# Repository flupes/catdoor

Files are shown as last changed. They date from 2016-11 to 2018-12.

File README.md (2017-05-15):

# catdoor
Cat door opening detection and notification

## First version

Notification of cat entry only (catdoor locked so that the cat can never go out, but always come in). This allows to make sure the cat in inside before dark in case we are coming late home.

### Sensing

Based on a proximity sensor looking down where the door opens. Some reflective on the side of the door allow a ver good signature, sorting out the cat. In fact, test of reflectivity on the cat hairs shows very poor reflection. Tuning the system as been done by observing serveral opening (look in the data directory)

- Microcontroller with ESP8266 Wifi:[Adafruit Feather HUZZAH with ESP8266 WiFi](https://www.adafruit.com/product/2821)
- Breadkout sensor board: [VCNL4010 Proximity/Light sensor](https://www.adafruit.com/product/466)

### Notification

The Feather HUZZAH sends a mqtt message to a Beagle Bone Black (BBB), which in turn sends notifications to a cell phone using Push Bullet.

The HUZZAH sends periodic updates of the door status, thus the BBB is can also detect potential anomalies.

This architecture with the HUZZAH + BBB never exposes the ESP8266 on the internet (only local communication).

## Second version

### Goals

- Outgoing locking mechanism that only allows the cat to go out during full daylight
- Notification of door actuation in the two direction (in and out)

Design ideas in ./design.md

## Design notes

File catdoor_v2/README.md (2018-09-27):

# Intro

This is the source directory for the version 2 of the catdoor application.

The code under this directory is structured to be compiled with platformio.

```
catdoor_v2/
├── app            main catdoor application
├── libs           libraries
└── tests          test programs (development purpose)
```                  

# Dependencies

## libs via platformio
Install the following:
- WiFi101 by Arduini - http://www.arduino.cc/en/Reference/WiFi101
- PubSubClient by Nick O'Leary - https://github.com/knolleary/pubsubclient.git

## extra libs

To get extra custom libraries like my fork of RTClib, use:
```
git submodules init
git submodules update
```

# Build and Install

Compile with:

    pio run -v

Upload with:

    pio run -v --target upload

Serial Monitor:
    pio device list
    pio device monitor --port /dev/cu.usbmodem1421 --baud 115200
      # or on PC:
    pio device monitor --port COM29 --baud 115200

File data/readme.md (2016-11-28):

### Record serial port
```
screen -L /dev/cu.SLAB-USBtoUART 115200
```
Note: output is `screenlog.0`, will overwrite a previous one...

Terminate session with: `Ctrl-a + \`

### Procedure

The vcnl4010_test program was flashed on the ESP8266 to record data using
screen.

### Files

#### Results
[`door_entry_signatures.svg`](./door_entry_signatures.svg) : graph of the door opening signatures

[`cat_only_returns.svg`](./cat_only_returns.svg) : sensor with Misty playing under it (door closed)

#### Analysis
`door_signatures.ods` : analysis of the data (signature, timing,
background)

#### Logs
`misty_entry_and_stay.log` : log with one entry (kind of messed up because
Misty stop right under the sensor after entering since the treat was there)

`misty_2_entries.log` : log with two entries in the same file

`misty_entry_?.log` : short version (5 seconds around the event) of the
previous logs

`misty_only_?.log` : door closed, but Misty under the sensor (playing with
my hand)

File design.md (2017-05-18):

# Design of the CatDoor v2

## Requirements

- System based on the [SureFlap Microchip Cat Door](https://sureflap.com/en-us/pet-doors/microchip-cat-flap)
  - right size
  - seems reliable (tested one for 1 year + reviews)
- The RFID entry (from outside) mechanism is left untouched
  - keep the same IN reliability
- Allow exit only during daylight
  - need very high reliability in locking (OK to lock too often, not OK to not lock once) to avoid having the cat becoming a Mountain Lion snack
  - ideally, timer follow seasonal sunset - surise times
- Notify of entrance / exit pattern to get some peace of mind when away, and be able to re-act quicly if cat did not come in before dark.

## Locking Solutions

### Servo + feedback

The servo arm would have two position at 90 deg to lock/unlock the door. The servo can be turned off all the time but when switching mode because there is enough friction to leave the arm in place.

Since the servo would not provide a default locked position (loss of power or other issue), a servo with analog feedback would be used: each time the mode it switched we could get confirmation that the actual position has been reached.

#### Pro
- Simple solution and micro servo available (e.g. https://www.adafruit.com/product/1449)

#### Cons
- This is not a totatlly safe proof solution
- If power is loss, we are operating from the LiPo 3.7V, thus probably requiring a voltage booster to power the servo

### Linear solenoid + proximity sensor

A small pull solenoid (default plunger position out) would be retracted when the cat approach the door.

#### Pro
- Safest solution: when eveything fails, the door is locked and the cat cannot go outside

#### Con
- Requires a an extra sensor ang good signal to trigger the opening
- Not easy to source miniature solenoids operating at low voltages
s
## Notes

There are two ohter products that do already the right in/out control with timer:
- [Cat Mate Elite](https://www.amazon.com/Cat-Mate-Elite-Timer-Control/dp/B000XPSH34). However it only seems to work with RFID chips you put on a colar. And multiple reviews mentioned it is not reliable. Since we cannot afford to have the cat locked out a single time, this product does not seems an option for our usage.

- [SureFlap Microchip Pet Door](https://www.amazon.com/SureFlap-Microchip-Pet-Door-White/dp/B009NH6NR0/). However this product is much larger (Pet vs Cat) than a normal cat door.
  - Pet Door Dimensions:
    - Flap Opening: 6 11⁄16" (W) x 7" (H)
    - Exterior Frame: 10 5⁄16" (W) x 11 1⁄16" (H)
  - Cat Door Dimensions:
    - Flap Opening: 5 5⁄8" x 4 3⁄4"
    - Exterior Frame: 8 1⁄4" (W) x 8 1⁄4" (H)

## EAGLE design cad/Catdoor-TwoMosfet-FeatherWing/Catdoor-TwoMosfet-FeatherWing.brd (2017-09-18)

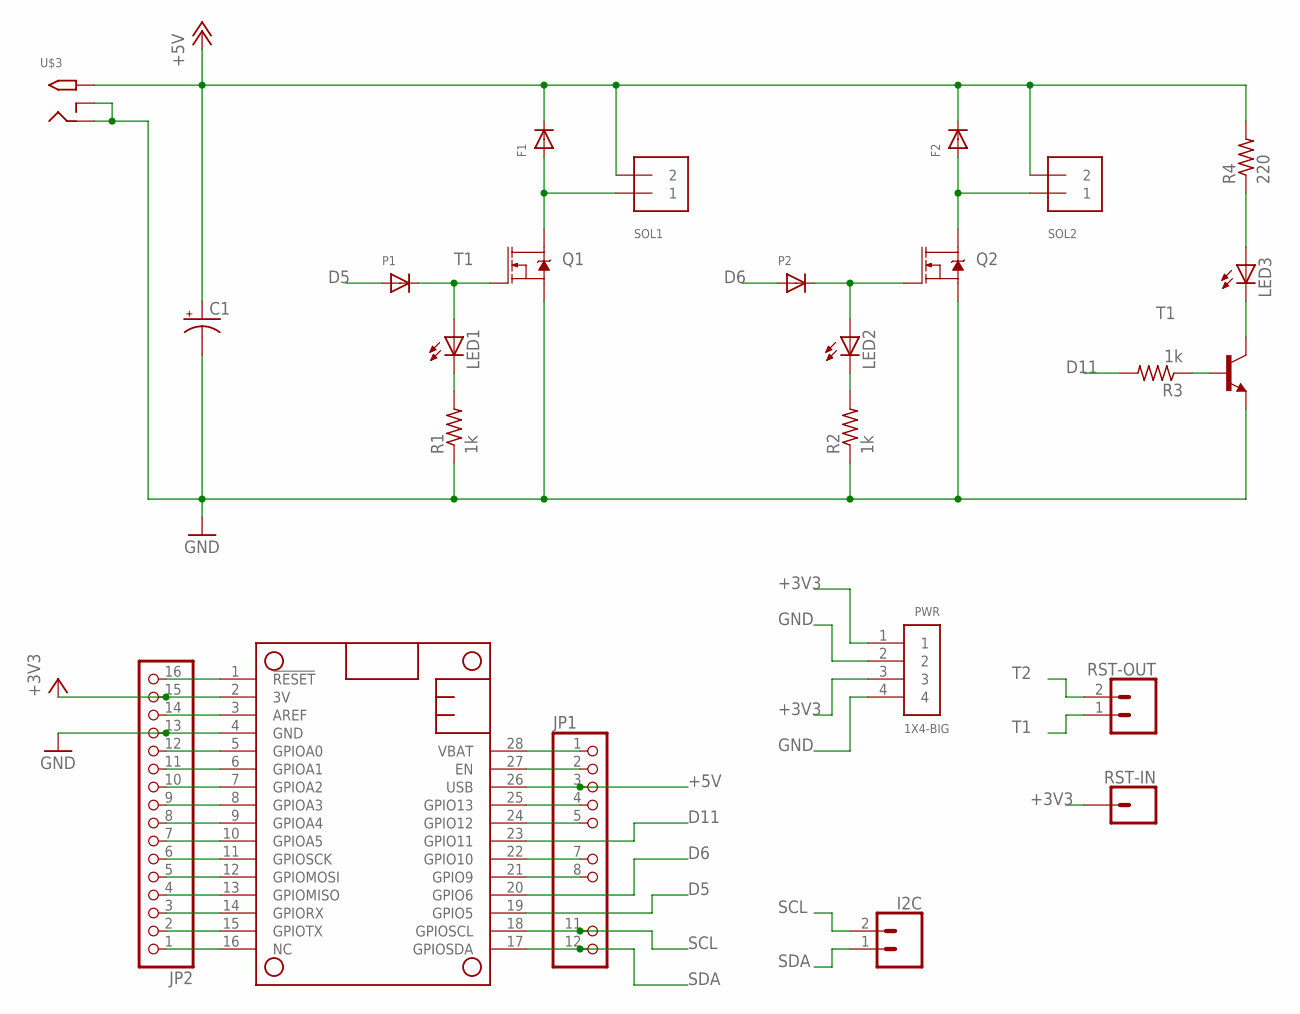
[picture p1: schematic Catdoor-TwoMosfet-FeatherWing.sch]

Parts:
C1: CPOL-USE5-13; E5-13
F1, F2: DIODELONG-SPACING; DIODE-LONG
I2C: CONN_02; 1X02
JP1: PINHD-1X12-CB; 1X12-CB
JP2: HEADER-1X16ROUND; 1X16_ROUND
LED1, LED2, LED3: LED3MM
MS1: FEATHERWING
P1, P2: DIODELONG-SPACING; DIODE-LONG
PWR: 1X4-BIG; 1X04-BIG
Q1, Q2: MOSFET-NCH-FQP30N06L; TO220V
R1, R2, R3: 1k; 0204/7
R4: 220; 0204/7
RST-IN: CONN_01; 1X01
RST-OUT: CONN_02; 1X02
SOL1, SOL2: TERMBLOCK_1X2; TERMBLOCK_1X2-3.5MM
T1: 2N2222; TO92-EBC-OVAL
U$3: 2.1MMJACKTHM; PJ-102A

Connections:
+3V3: JP2.15, MS1.2 (3V), PWR.1, PWR.3, RST-IN.1
+5V: C1.+, F1.C, F2.C, JP1.3, MS1.26 (USB), R4.2, SOL1.2, SOL2.2, U$3.TIP
D5: MS1.19 (GPIO5), P1.A
D6: MS1.20 (GPIO6), P2.A
D11: MS1.23 (GPIO11), R3.2
GND: C1.-, JP2.13, MS1.4 (GND), PWR.2, PWR.4, Q1.3 (S), Q2.3 (S), R1.1, R2.1, T1.E, U$3.RING, U$3.RING_SW
unnamed: JP1.2, MS1.27 (EN)
unnamed: JP1.4, MS1.25 (GPIO13)
unnamed: LED3.A, R4.1
unnamed: LED1.K (C), R1.2
unnamed: JP1.5, MS1.24 (GPIO12)
unnamed: LED3.K (C), T1.C
unnamed: R3.1, T1.B
unnamed: LED2.K (C), R2.2
unnamed: JP1.7, MS1.22 (GPIO10)
unnamed: JP1.8, MS1.21 (GPIO9)
unnamed: JP2.1, MS1.16 (NC)
unnamed: JP2.2, MS1.15 (GPIOTX)
unnamed: JP2.3, MS1.14 (GPIORX)
unnamed: JP2.4, MS1.13 (GPIOMISO)
unnamed: JP2.5, MS1.12 (GPIOMOSI)
unnamed: JP2.6, MS1.11 (GPIOSCK)
unnamed: JP2.7, MS1.10 (GPIOA5)
unnamed: JP2.8, MS1.9 (GPIOA4)
unnamed: JP2.9, MS1.8 (GPIOA3)
unnamed: JP2.10, MS1.7 (GPIOA2)
unnamed: JP2.11, MS1.6 (GPIOA1)
unnamed: JP2.12, MS1.5 (GPIOA0)
unnamed: JP2.14, MS1.3 (AREF)
unnamed: JP2.16, MS1.1 (!RESET)
S1: F1.A, Q1.2 (D), SOL1.1
S2: F2.A, Q2.2 (D), SOL2.1
SCL: I2C.2, JP1.11, MS1.18 (GPIOSCL)
SDA: I2C.1, JP1.12, MS1.17 (GPIOSDA)
T1: LED1.A, P1.C, Q1.1 (G), RST-OUT.1
T2: LED2.A, P2.C, Q2.1 (G), RST-OUT.2
VBAT: JP1.1, MS1.28 (VBAT)

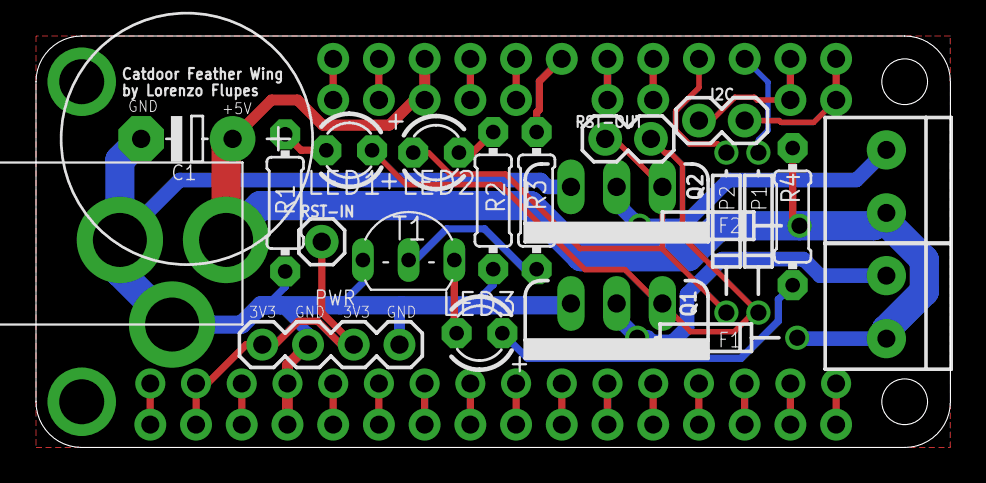
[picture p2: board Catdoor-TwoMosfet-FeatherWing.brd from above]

Board: 2 copper layers, 50.8 x 22.9 mm, 25 parts (0 on the bottom side), 37 nets.

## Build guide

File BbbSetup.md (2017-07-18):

## Setup the Beagle Bone Black

### Prepare the image
Download:<br>
  `bone-debian-8.6-iot-armhf-2016-11-06-4gb.img.xz`
  
From:<br>
  https://debian.beagleboard.org/images/

Verify checksum:
```
  sha256sum.exe bone-debian-8.6-iot-armhf-2016-11-06-4gb.img.xz
```
against:
```
  bone-debian-8.6-iot-armhf-2016-11-06-4gb.img.xz.sha256sum
```

Burn to SD card using Win32DiskImager (if on Windows…)

### Boot from the SD card
1. Card not powered
2. Insert SD card
3. Press the boot button (next to the microSD card) 
4. Apply power from host computer using mini-USB connector (next to eth)
5. Let boot (only USR0 LED flashing)
6. Log on the board: ssh debian@192.168.7.2 (temppwd)

### Flash eMMC
1. `cd /opt/scripts/tools/eMMC`
2. `sudo bash`
3. `./init-eMMC-flasher-v3.sh`
4. remove power
5. remove SD-card
6. connect ethernet cable
7. apply power

### De-bloat
Inspired from:
  * http://kacangbawang.com/beagleboneblack-revc-debloat-part-1/
  * https://hacks.pmf.io/2015/06/21/securing-the-beaglebone-black/

```
#sudo apt-get purge xrdp
sudo apt-get purge -y bone101
sudo apt-get purge -y c9-core-installer
sudo apt-get purge -y bb-node-red-installer
sudo apt-get purge -y bonescript
sudo apt-get purge -y apache2 apache2-bin apache2-data apache2-utils
sudo apt-get autoremove
```

### Update the distro
```
sudo apt-get update
sudo apt-get dist-upgrade
```

### Set the time zone
Select the right time zone
```
sudo dpkg-reconfigure tzdata
```

Old manual method, just for reference:
```
cd /etc
sudo mv localtime localtime.org
sudo ln -s /usr/share/zoneinfo/America/Los_Angeles /etc/localtime
```

### Setup ntp
```
sudo apt-get install -y ntp
```

### Change the hostname
```
sudo vi /etc/hostname
sudo vi /etc/hosts
sudo reboot
```

### Install extra packages
```
sudo apt-get install -y emacs24-nox
sudo apt-get install -y byobu
```

### Secure
```
passwd debian
sudo passwd root
```

### Configure
```
sudo apt-get install mosquitto mosquitto-clients

```

### Python MQTT client
Install Paho: https://pypi.python.org/pypi/paho-mqtt
```
sudo pip install paho-mqtt
```

### Pushbullet Python
```
sudo pip install pushbullet.py
```

### Setup pushbullet credentials
Retrieve your pushbullet password and create a `~/.netrc` file of the sort:
```
machine catdoor
login your_email_address
password your_pushbullet_password
```
The `.netrc` files should be readable only by the user:
```
chmod go-r ~/.netrc
```

### Install service
```
# from the catdoor directory
mkdir logs
cd scripts
# edit the catdoor.service and start-catdoor.bash files to reflect where
# the repo has been checked-out
# make the systemd unit owned by root (otherwise if will not start automatically at boot)
sudo chown root.root catdoor.service
# enable using the full path to the unit
sudo systemctl enable /home/debian/catdoor/scripts/catdoor.service
```

### Some info

#### LEDS
Boot configuration:
  - USR0 is configured at boot to blink in a heartbeat pattern
  - USR1 is configured at boot to light during microSD card accesses
  - USR2 is configured at boot to light during CPU activity
  - USR3 is configured at boot to light during eMMC accesses

http://robotic-controls.com/learn/beaglebone/beaglebone-black-built-leds

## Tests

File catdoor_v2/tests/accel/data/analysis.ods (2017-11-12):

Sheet: closed
 | X | Z
mean | -16110 | -217
std | 31 | 41
min | -16208 | -352
max | -16016 | -128
 | -16160 | -240
 | -16128 | -176
 | -16096 | -224
 | -16080 | -240
 | -16112 | -272
 | -16160 | -272
 | -16112 | -256
 | -16112 | -256
 | -16064 | -240
 | -16064 | -240
 | -16096 | -160
 | -16112 | -144
 | -16096 | -192
 | -16112 | -272
 | -16112 | -192
 | -16144 | -176
 | -16144 | -224
 | -16144 | -240
 | -16112 | -192
 | -16064 | -144
 | -16064 | -192
 | -16064 | -160
 | -16080 | -176
 | -16096 | -192
 | -16080 | -160
 | -16112 | -224
 | -16144 | -288
 | -16096 | -288
 | -16096 | -272
 | -16112 | -208
 | -16160 | -208
 | -16160 | -192
 | -16160 | -192
 | -16144 | -256
 | -16128 | -256
 | -16128 | -208
 | -16112 | -144
 | -16112 | -144
 | -16112 | -128
 | -16080 | -176
 | -16080 | -144
 | -16096 | -176
 | -16096 | -208
 | -16080 | -208
 | -16080 | -192
 | -16064 | -256
 | -16144 | -240
 | -16112 | -256
 | -16096 | -304
 | -16096 | -320
 | -16096 | -272
 | -16144 | -272
 | -16080 | -176
 | -16080 | -208
 | -16096 | -288
 | -16096 | -240
 | -16064 | -256
 | -16112 | -240
 | -16096 | -144
 | -16128 | -208
 | -16128 | -192
 | -16112 | -208
 | -16144 | -176
 | -16080 | -208
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

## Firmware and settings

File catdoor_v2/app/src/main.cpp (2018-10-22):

#include "RTClib.h"
#include "accel.h"
#include "daytimes.h"
#include "ledctrl.h"
#include "m0_hf_pwm.h"
#include "mqtt_client.h"
#include "netcfg.h"
#include "proxim.h"
#include "solenoids.h"
#include "utils.h"
#include "watchdog_timer.h"

// For float to string formatting
#include <avr/dtostrf.h>

// Where to get the battery voltage
#define VBATPIN A7

// Customization for acceptable daylight times
static const TimeSpan margin_after_sunrise(0, 2, 0, 0);
static const TimeSpan margin_before_sunset(0, 4, 0, 0);

static const unsigned long LOOP_PERIOD_MS = 25;
static const uint8_t AJAR_OUT_COUNT_TO_JAMMED = 2 * 1000 / LOOP_PERIOD_MS;

static const unsigned long STAY_OPEN_WIHOUT_CAT_SEC = 30;

// To debug during dark period
static const bool debug_mode = false;

// global objects...
RTC_DS3231 rtc;
Accel accel_sensor;
Proxim proxim_sensor;
Solenoids& sol_actuators = Solenoids::Instance();
LedCtrl& status_led = LedCtrl::Instance();
WiFiClient wifi_client;
MQTT_Client mqtt_client(wifi_client, status_led);

// interupts function prototypes
void accelReady() { accel_sensor.data_ready_ = true; }

void setup() {
  wdt_configure(11);

  // HF PWM
  pwm_configure();

  // let things stabilize before pulling too much current
  // not necessary, but surprise the developer less also
  delay(1000);

  // Force unjam, no matter what, just in case we rebooted
  // Also this says Hi to the world
  sol_actuators.unjam();

  // start in unkown state
  status_led.warning();

#ifdef USE_SERIAL
  Serial.begin(115200);
  while (!Serial) {
    ;  // wait for serial port to connect to start the app
  }
// Serial.print("sizeof(int)=");
// Serial.println(sizeof(int));
#endif

  //
  // Accelerometer setup
  //
  if (!accel_sensor.begin(0x18)) {
    PRINTLN("Couldnt start accelerometer!");
    while (1)
      ;
  }
  PRINTLN("LIS3DH found.");

  // configure sensor
  accel_sensor.setDataRate(LIS3DH_DATARATE_25_HZ);
  accel_sensor.setRange(LIS3DH_RANGE_2_G);

  // attach hardware interrupt
  pinMode(A2, INPUT_PULLUP);
  attachInterrupt(A2, accelReady, RISING);
  delay(1);             // for some reason, this delay is CRITICAL!
  accel_sensor.read();  // read reset the signal --> start interrupts
  delay(1);
  accel_sensor.calibrate();

  //
  // Proximity sensor setup
  //
  if (!proxim_sensor.begin()) {
    PRINTLN("Sensor not found :(");
    while (1)
      ;
  }
  PRINTLN("Found VCNL4010");
  proxim_sensor.init();

  // RTC
  if (!rtc.begin()) {
    PRINTLN("Couldn't find RTC!");
    while (1)
      ;
  }

  // Configure pins for Adafruit ATWINC1500 Feather
  WiFi.setPins(8, 7, 4, 2);
  // Check for the presence of the shield
  PRINTLN("Connecting to the Wifi module...");
  if (WiFi.status() == WL_NO_SHIELD) {
    PRINTLN("WiFi shield not present");
    return;  // don't continue
  }

  mqtt_client.connect_wifi(MY_WIFI_SSID, MY_WIFI_PASS);
  status_led.warning();  // not done yet with setup!
  mqtt_client.setServer(MQTT_SERVER, MQTT_PORT);
  mqtt_client.connect_client();
  status_led.warning();  // not done yet with setup!

  PRINTLN("MQTT client connected.");
  const char* msg = "Catdoor v2 started";
  DateTime utc_time = rtc.now();
  unsigned int now = millis();
  DateTime local_time = utc_time.getLocalTime(TIME_ZONE_OFFSET);
  mqtt_client.sync_time(local_time, now);
  mqtt_client.publish_timed_msg(now, TOPIC_MESSAGE, msg);
  // start by flashing like in the darkness..
  status_led.alive();

  wdt_configure(4);
}

void loop() {
  static bool cat_exiting = false;
  static bool daylight = false;
  static bool rtc_read = true;
  static unsigned long last_time = millis();
  static unsigned long last_unjam = last_time;
  static unsigned long door_clear_time = last_time;
  unsigned long now = millis();
  unsigned long elapsed;
  unsigned long sleep_ms;
  static Solenoids::state_t prev_actuators_state = Solenoids::OFF;
  static char buffer[24];
  static uint8_t jammed_counter = 0;

  if ((now - last_time) > 10 * 1000) {
    if (rtc_read) {
      // Check RC every 20s
      DateTime ltime = rtc.now().getLocalTime(TIME_ZONE_OFFSET);
      mqtt_client.sync_time(ltime, now);
      uint16_t day = ltime.yDay();
      if (day == 366)
        day = 1;  // We will be one day offset for all leap years...
      DateTime sunrise(ltime.year(), ltime.month(), ltime.day(),
                       sunset_sunrise_times[day - 1][0],
                       sunset_sunrise_times[day - 1][1], 0, TIME_ZONE_OFFSET);
      DateTime sunset(ltime.year(), ltime.month(), ltime.day(),
                      sunset_sunrise_times[day - 1][2],
                      sunset_sunrise_times[day - 1][3], 0, TIME_ZONE_OFFSET);
      DateTime morning = sunrise + margin_after_sunrise;
      DateTime afternoon = sunset - margin_before_sunset;
      if (false || (morning < ltime && ltime < afternoon)) {
        status_led.ok();  // safe to repeat without breaking the pattern
        if (!daylight) {
          daylight = true;
          sprintf(buffer, "%s %d:%d", "UNLOCKED", afternoon.hour(),
                  afternoon.minute());
          mqtt_client.publish_timed_msg(now, TOPIC_MESSAGE, buffer);
        }
      }  // if daylight
      else {
        status_led.alive();  // safe to repeat without breaking the pattern
        if (daylight) {
          daylight = false;
          sprintf(buffer, "%s %d:%d", "LOCKED", morning.hour(),
                  morning.minute());
          mqtt_client.publish_timed_msg(now, TOPIC_MESSAGE, buffer);
        }
      }  // else daylight
      rtc_read = false;
      mqtt_client.publish_timed_msg(now, TOPIC_HEARTBEAT,
                                    daylight ? "DAYLIGHT" : "DARK");
    } else {
      // alternate with reading the battery voltage
      float measuredvbat = analogRead(VBATPIN);
      measuredvbat *= 2;     // we divided by 2, so multiply back
      measuredvbat *= 3.3;   // Multiply by 3.3V, our reference voltage
      measuredvbat /= 1024;  // convert to voltage
      char num[6];
      dtostrf(measuredvbat, 5, 2, num);
      // char str[12];
      // sprintf(str, "VBAT %s", num);
      mqtt_client.publish_timed_msg(now, TOPIC_BATTERY_V, num);
      rtc_read = true;
    }

    last_time = now;
  }  // if 10s

  // Process accelerometer
  if (accel_sensor.data_ready_) {
    accel_sensor.process();
    if (accel_sensor.new_state_) {
      accel_sensor.new_state_ = false;
      mqtt_client.publish_timed_msg(
          now, TOPIC_DOORSTATE,
          ACCEL_STATES_NAMES[(uint8_t)accel_sensor.state_]);
    }
  }

  // Check if cat is in front of door
  if (proxim_sensor.new_state) {
    proxim_sensor.process();
    if (proxim_sensor.state == Proxim::CAT) {
      PRINTLN("CAT");
      mqtt_client.publish_timed_msg(now, TOPIC_PROXIMITY, "CAT");
      if ((daylight || debug_mode) && accel_sensor.state_ == Accel::CLOSED) {
        // Retract the door locks!
        if (sol_actuators.state() == Solenoids::OFF) {
          sol_actuators.open();
          mqtt_client.publish_timed_msg(now, TOPIC_SOLENOIDS, "RETRACTED");
        }
      }
    } else {
      PRINTLN("CLEAR");
      door_clear_time = now;
      mqtt_client.publish_timed_msg(now, TOPIC_PROXIMITY, "CLEAR");
    }
  }

  // Release if the cat is not detected after some time (to avoid a HOT_RELEASE
  // much later)
  if (proxim_sensor.state == Proxim::CLEAR &&
      sol_actuators.state() == Solenoids::ON &&
      accel_sensor.state_ == Accel::CLOSED &&
      (now - door_clear_time) > STAY_OPEN_WIHOUT_CAT_SEC * 1000) {
    sol_actuators.release();
    mqtt_client.publish_timed_msg(now, TOPIC_SOLENOIDS, "RELEASE");
  }

  // Mark that cat is going out (to release the solenoids later)
  if (sol_actuators.state() == Solenoids::ON &&
      accel_sensor.state_ == Accel::OPEN_OUT) {
    cat_exiting = true;
  }

  // Release solenoids if cat finished exiting
  if (cat_exiting && accel_sensor.state_ == Accel::CLOSED &&
      sol_actuators.state() == Solenoids::ON &&
      proxim_sensor.state == Proxim::CLEAR) {
    sol_actuators.release();
    mqtt_client.publish_timed_msg(now, TOPIC_SOLENOIDS, "RELEASE");
    cat_exiting = false;
  }

  // Detect jammed condition and try to resolve it
  if (accel_sensor.state_ == Accel::AJAR_OUT &&
      sol_actuators.state() == Solenoids::OFF) {
    jammed_counter++;
    if (jammed_counter > AJAR_OUT_COUNT_TO_JAMMED) {
      // need to "debounce" this jammed condition because
      // sudden air flow can trigger an AJAR_OUT
      if ((now - last_unjam) > Solenoids::COOLDOWN_DURATION_MS) {
        last_unjam = now;
        sol_actuators.unjam();
        mqtt_client.publish_timed_msg(now, TOPIC_SOLENOIDS, "UNJAM");
      }
    }
  }

  // Check a hot release
  if (sol_actuators.state() != prev_actuators_state) {
    if (prev_actuators_state == Solenoids::ON &&
        sol_actuators.state() == Solenoids::HOT) {
      mqtt_client.publish_timed_msg(now, TOPIC_SOLENOIDS, "HOT_RELEASE");
    }
    prev_actuators_state = sol_actuators.state();
  }

  if (accel_sensor.state_ == Accel::CLOSED) {
    jammed_counter = 0;
  }

  // Let the MQTT client do some work
  mqtt_client.loop();

  elapsed = millis() - now;
  if (elapsed > LOOP_PERIOD_MS) {
    PRINT("==== warning, loop overrun: ");
    PRINTLN(elapsed);
    mqtt_client.publish_timed_msg(now, TOPIC_MESSAGE, "LOOP OVERRUN");
    sleep_ms = 0;
  } else {
    sleep_ms = LOOP_PERIOD_MS - elapsed;
  }

  // Say we are still alive!
  wdt_reset();

  // Loop is variable period, but we do not really care...
  delay(sleep_ms);
}

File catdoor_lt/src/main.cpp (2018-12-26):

#include <Arduino.h>

#include <RTCZero.h>

#include "basic_ntp.h"
#include "m0_hw_servo.h"
#include "netcfg.h"
#include "utils.h"
#include "watchdog_timer.h"

#define MAX_JAMMED_COUNT 5
#define UPDATE_MOT_PERIOD_MS 1000 * 2
#define UPDATE_NET_PERIOD_MS 1000 * 20

const uint8_t MORNING_HOUR = 8;
const uint8_t EVENING_HOUR = 17;

const uint32_t kClosedVoltageCount = 800;
const uint32_t kOpenVoltageCount = 2900;

M0HwServo servo(M0HwServo::D5, A1);

long g_lastReconnectAttempt = 0;
long g_lastMasterUpdate = 0;

enum LockState { CLOSED = 0, OPEN = 1, JAMMED = 2 };
static const char* STATE_NAMES[] = {"CLOSED", "OPEN", "JAMMED"};

LockState g_desiredDoorState = CLOSED;
bool g_autoLockMode = false;

AdafruitIO_Feed* command = g_io.feed("door-cmd");
AdafruitIO_Feed* state = g_io.feed("door-state");
AdafruitIO_Feed* battery = g_io.feed("door-battery");

RTCZero g_rtc;

void print_time() {
  PRINT("RTC Time = ");
  uint8_t hh = g_rtc.getHours();
  uint8_t mm = g_rtc.getMinutes();
  uint8_t ss = g_rtc.getSeconds();
  if (hh < 10) PRINT("0");
  PRINT(hh);
  PRINT(":");
  if (mm < 10) PRINT("0");
  PRINT(mm);
  PRINT(":");
  if (ss < 10) PRINT("0");
  PRINTLN(ss);
}

void handle_message(AdafruitIO_Data* data) {
  PRINT("received <- ");
  int value = data->toInt();
  PRINTLN(value);
  if (value == 2) {
    PRINTLN("automatic mode");
    g_autoLockMode = true;
  } else {
    g_autoLockMode = false;
    g_desiredDoorState = CLOSED;
    if (value == 1) {
      g_desiredDoorState = OPEN;
      PRINTLN("commanded to open");
    }
  }
}

void setup() {
#ifdef USE_SERIAL
  Serial.begin(115200);
  int wait_sec = 0;
  while (!Serial) {
    delay(1000);
    wait_sec++;
    if (wait_sec > 12) break;  // wait no more than 12s for a connection...
  }
#endif

  servo.Configure(450, 0, 2050, 120);
  // We always start in a closed state!
  // for our setup closed is MIN position, but be careful
  // to adjust is setup changes!
  servo.SetDegreeAngle(servo.GetMinDegreeAngle());

  g_rtc.begin();

  wdt_configure(11);

  // connect to g_io.adafruit.com
  PRINT("Connecting to Adafruit IO");
  g_io.connect();

  PRINTLN(g_io.connectionType());
  PRINTLN(g_io.networkStatus());

  command->onMessage(handle_message);

  // wait for a connection
  while (g_io.status() < AIO_CONNECTED) {
    PRINT(".");
    // PRINTLN(g_io.statusText());
    delay(1000);
  }

  // we are connected
  PRINTLN();
  PRINTLN(g_io.statusText());

  PRINT("Get time sync");
  time_t ts = 0;
  uint8_t nb_tries = 0;
  while (ts == 0 && nb_tries < 5) {
    PRINT(".");
    ts = get_local_ntp_time();
    nb_tries++;
  }

  if (ts == 0) {
    PRINTLN("Failed to get a time sync!");
  } else {
    g_rtc.setEpoch(ts);
    print_time();
  }

  // Force update
  command->get();

  WiFi.lowPowerMode();

  g_lastMasterUpdate = millis();
}

void loop() {
  static const int closed_deg = servo.GetMinDegreeAngle();
  static const int open_deg = servo.GetMaxDegreeAngle();

  static long elapsed_mot = millis();
  static long elapsed_net = millis();
  static int jammed_counter = MAX_JAMMED_COUNT;
  static LockState lock_state = JAMMED;

  long now = millis();

  // if (now - g_lastMasterUpdate > 45000) {
  //   // close if no update from master
  //   g_desiredDoorState = CLOSED;
  // }

  g_io.run();

  if (now - elapsed_mot > UPDATE_MOT_PERIOD_MS) {
    elapsed_mot = now;
    uint32_t current_voltage_count = servo.GetAveragedAnalogFeedback(3);

    jammed_counter--;
    if (current_voltage_count < kClosedVoltageCount) {
      lock_state = CLOSED;
      jammed_counter = MAX_JAMMED_COUNT;
    }
    if (current_voltage_count > kOpenVoltageCount) {
      lock_state = OPEN;
      jammed_counter = MAX_JAMMED_COUNT;
    }
    if (jammed_counter < 1) {
      lock_state = JAMMED;
      PRINTLN("JAMMED!!!");
    }

    if (g_autoLockMode) {
      uint8_t hh = g_rtc.getHours();
      g_desiredDoorState = CLOSED;
      if (MORNING_HOUR <= hh && hh <= EVENING_HOUR) {
        g_desiredDoorState = OPEN;
      }
    }
    if (g_desiredDoorState != lock_state) {
      if (g_desiredDoorState == OPEN) {
        servo.SetDegreeAngle(open_deg);
      } else {
        servo.SetDegreeAngle(closed_deg);
      }
    }
  }

  if (now - elapsed_net > UPDATE_NET_PERIOD_MS) {
    elapsed_net = now;
    PRINT("door state = ");
    PRINTLN(STATE_NAMES[lock_state]);
    state->save(lock_state);

    float measuredvbat = analogRead(A7);
    measuredvbat *= 2;     // we divided by 2, so multiply back
    measuredvbat *= 3.3;   // Multiply by 3.3V, our reference voltage
    measuredvbat /= 4096;  // convert to voltage (12 bits)
    PRINTLN("VBat: ");
    PRINTLN(measuredvbat);
    battery->save(measuredvbat);
  }

  wdt_reset();
  delay(200);
}

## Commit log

2016-11-20 added an extra directory level because of the stupid Arduino IDE (need to go back to CMake)
2016-11-21 follow the Arduino IDE constraints for the extra .ino programs
2016-11-26 New version without the schedulers: Using Ticker was nicer, but caused occasional crashes. Exceptions (9) "Load or store to an # unaligned address" was triggered inside the Adafruit VCNL4010 (readPro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
    [catdoor.ino]
2016-11-27 reboot the esp8266 after a number of client reconnect retries
    [catdoor.ino]
2016-11-27 proximity printer to record door signature
2016-11-28 added recorded logs and analysis
    [door_signatures.ods]
2017-07-24 added SolveSpace CAD file for solenoid mount
2017-07-30 added first test for solenoid actuation
2017-09-04 controls now 3 independant PWM (D5, D6 and D11)
2017-09-04 added fritzing circuit for fun
    [circuit.fzz]
2017-09-05 improved layout
    [catdoor_shield.fzz, circuit.fzz]
2017-09-17 added second version of the circuit board (using Eagle)
    [Catdoor-TwoMosfet-FeatherWing.brd, Catdoor-TwoMosfet-FeatherWing.sch]
2017-09-17 improved the silk screen
    [Catdoor-TwoMosfet-FeatherWing.brd]
2017-09-18 version sent for fab
    [Catdoor-TwoMosfet-FeatherWing.brd]
2017-09-24 ported the pure arduino project to atom/platformio
2017-11-05 working solution for proximity interrupts (but not cleaned yet)
2017-11-05 added a standalone proximity sensor test to ease debugging
2017-11-05 added individual accelerometer test
2017-11-05 force the pwm to zero at startup
2017-11-05 collected some data for analysis
    [analysis.ods, closed.csv, in_limits.csv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]
2017-11-05 application with correct state machine
    [main.cpp]
2017-11-06 added RTC, LED status and daylight control
2017-11-08 broke facilities in multiples files and fixed interrupt management
2017-11-08 publish the PWM signal traces
2017-11-08 new version of the app incorporating all the other fixes: seems to work much better
    [main.cpp]
2017-11-12 added more tests to understand the bad interaction of the RTC with the accelerometer
    [analysis.ods]
2017-11-12 fixed some state machine, added battery monitoring and mqtt support
    [main.cpp]
2017-11-16 added a watchdog timer functionality with LONG periods
2017-11-16 managed the LED in the background with a Timer(TC) + ISR and created and VisualFeedback interface
2017-11-16 simplified and improved the main app using the new mqtt wrapper, auto led update and VisualFeedback
2017-11-17 re-factored in clean/safe classes and made Solenoids state machine updated by the internal timer
2017-11-17 have the correct led DARK/DAYLIGH status restored correctly after a network outage
    [main.cpp]
2017-11-18 lower ISR interrupt for LedCtrl + Solenoids and prepare for deployment
2017-11-18 adapted to the new Solenoids control and finalized the app
2017-11-20 Added battery monitoring and time synchronization check
2017-11-20 tuned the threshold for the proximity sensor
2017-11-20 Added a solenoid release condition if the cat is not well decided + some tuning
2017-11-20 increased the solenoid open max time based on some better experimentation
2017-11-27 fixed bug in battery state analysis
2017-11-29 Try a calibration routine
2018-09-30 re-tuned the proximity sensor
2018-10-17 disable battery notifications and fixed LOCKED/UNLOCKED messages
2018-12-02 started Catdoor Light: HW PWM servo control with feedback
2018-12-09 added a simple pusher watching a file and a printer
2018-12-09 added a simple test showing the analog feedback of the servo
2018-12-09 started real structure with mqtt and servo
2018-12-10 servo responding to door master
2018-12-16 working board + master programs

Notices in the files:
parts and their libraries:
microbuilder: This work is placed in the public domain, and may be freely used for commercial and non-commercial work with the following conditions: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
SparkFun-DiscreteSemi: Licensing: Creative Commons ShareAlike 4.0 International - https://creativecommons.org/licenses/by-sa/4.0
